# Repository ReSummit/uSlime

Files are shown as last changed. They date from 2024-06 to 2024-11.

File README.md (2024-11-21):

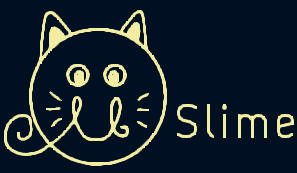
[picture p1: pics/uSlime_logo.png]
<div></div>

Micro form of SlimeVR trackers using BNO085 and ESP32-C6-MINI module, as small as possible

Limited to 1 sided PCB but utilizes two layer to achieve a maximal dimension of 25mm x 28mm (including the ESP32-C6-MINI module)

Also includes some test points if you wanna add idk RGB lights to it or something like that lol

## PCB Variants and Versions

Currently, v1.0.0 is the preferred PCB version and is listed in the releases. As a note, your red charge LED will always be on while the device is on. While this makes for a good indicator that your tracker is on, some may not like that the LED is always on. v1.1.0 fixes this but results in a long trace, change in pinout, and additional components needed.

**If you do not mind the always on LED, use v1.0.0 as it is less likely to result in RF issues. If you are bothered by the LED, use a 2k or higher SMD resistor value or use v1.1.0.**

On variants, there are currently three different types of main board PCBs and 2 types of supplementary modules. The first kind are listed as follows:
* uSlime_PCB: The default PCB with the BNO085 circuit on board. Contains the working BNO085 utilizing the internal crystal (of which there is little room for an external crystal)
* uSlime_PCB_Module: Similar to the default PCB; however, the BNO085 is replaced with a 5 pin I2C pin for attaching a uSlime_BNO085_Module on the back or front side of the PCB (in case you want to replace the IMU with a better one).
* uSlime_PCB_Pack: The default PCB but using pack resistors to attempt the reduction of part placements by quantity. **This has not been updated to v1.0.0 yet, DO NOT USE.**

For supplementary modules, the variants are as follows:
* uSlime_BNO085_Module: The default PCB for supplementary modules. In addition to the connectors that are compatible with the original SlimeVR trackers, they also have headers that you can use to connect it to something else instead if you decide not to use it for SlimeVR. This increases the versatility of the IMU for other projects. Due to the small size, a crystal could not be placed; however, one could be placed with a slightly larger PCB size.
* uSlime_BNO085: The other PCB for supplementary modules without the header pins. This is if you are sure that you are only using this for SlimeVR. You can technically still use this for other projects like with headers, but you will likely solder on wires.

## BOM and Pre-requisites

Bill of materials (BOMs) can be found in the `bom` folder within the respective PCB folder. These are generated on a by release basis, so they may not be up to date. It is highly recommended to generate the BOM using the "`Interactive Html Bom`" plugin found in typical KiCAD repository plugins.  
**Following the BOM placements using a BOM plugin to show where components are placed is mandatory, as there is no space for reference designators on the PCB.**

In addition to this, a hot plate, solder paste, and some needle tipped tweezers are also required. Flux may also be needed to fix any bridges that pop up on the board. Obviously, the components on the BOM are also required.

## Building the PCB

When ordering the PCB, choose to place the JLC PCB indicator as a preferred spot is placed on the PCB itself (if using JLCPCB for PCB production). You should also get a stencil to put solder paste on the PCB.

**Again, following the BOM placements using a BOM plugin to show where components are placed is mandatory, as there is no space for reference designators on the PCB.**
Place solder paste on the PCB. Afterwards, follow the Interactive HTML BOM to place all the capacitors, resistors, IMU, and MCU on the PCB. When ready, you can then place this on a hot plate. Please make sure that there are no bridges on the BNO085 or the USB C connector, as these can cause issues with functionality.

## Verification (MUST READ)

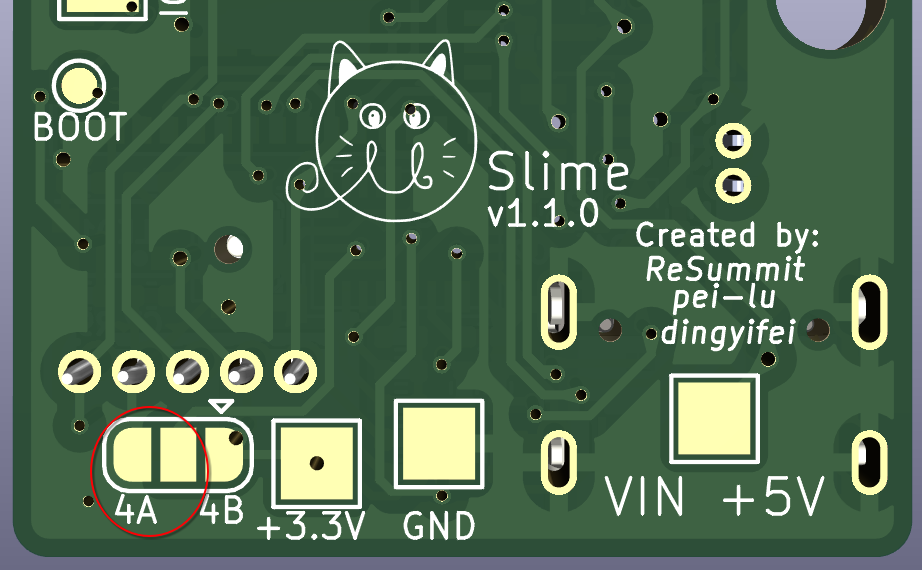
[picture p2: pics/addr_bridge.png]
<div><center>   

**Before testing and using, make sure to bridge the address bridge pads on the back of the PCB.** Verify that the board and the IMU functions by flashing the ESP32-C6 firmware first. If there is no address response, something may be wrong with the IMU (more likely to fail). Once you have verified that the IMU and MCU works, you can then solder the rest of the THT components such as the external IMU connector and battery connector.

## Firmware

The PCB currently uses a ESP32-C6 or equivalent MCU. Right now, there is a pull request to introduce this MCU into the SlimeVR ESP32 firmware located here:  
[SlimeVR ESP32-C6 Pull Request](https://github.com/SlimeVR/SlimeVR-Tracker-ESP/pull/327)

The Arduino core is technically updated but is still pending its full support to the ESP32-C6 line. Therefore, treat this as a beta firmware and subject to broken features or bugs.

## PCB Limitations

Due to the inherent nature of this PCB, there is a chance that this PCB may produce RF. We have not tested for RF emission but regardless, be careful if using this in RF restricted environments.

Also, the main PCB does not have USB voltage protection circuits! Unfortunately, we ran out of time for the release but it is plausible to add it...

In addition, due to the single-sided PCB layout, this is not technically as small as it could be. There have been countless videos that showcase the design possibly being smaller. Some resistor and SMD components can also be moved to the back due to the ease in soldering those components. However, those are slated for a v2.0.0 PCB and is not expected to be released within anytime this year.

Lastly, it is known that the charger SMD compoenent tends to heat up rather quickly while charging the battery. This shouldn't reach the melting point of solder but it is worth mentioning; perhaps a more efficient IC would be better here.

## Images:
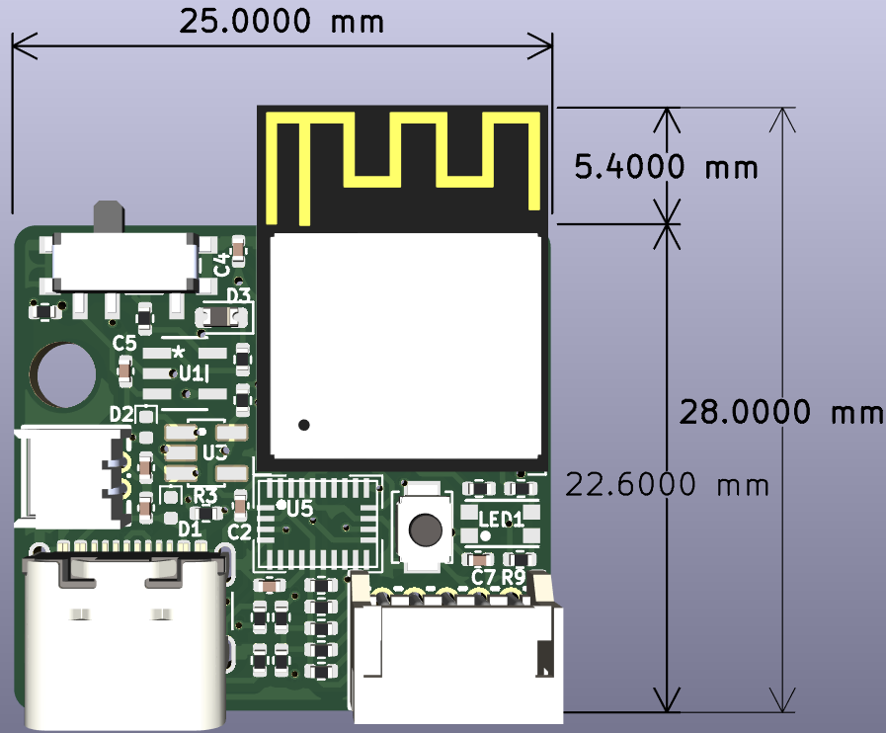
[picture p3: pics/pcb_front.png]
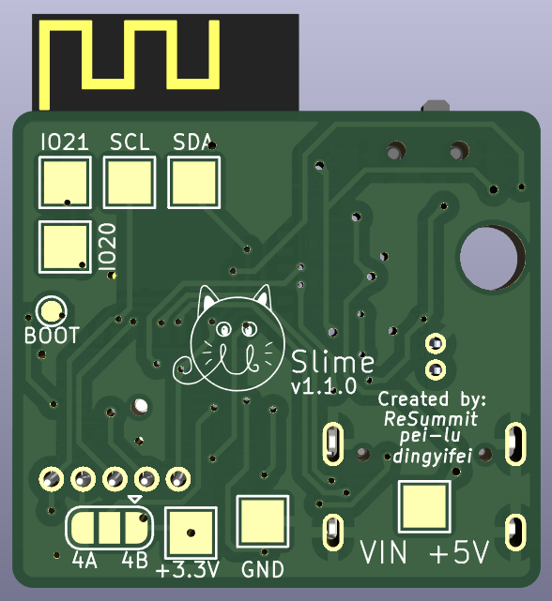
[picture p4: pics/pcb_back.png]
<div></div>

## Footprints Used

Some footprints and symbols were used from other sources:
* ESP32-C6 Symbol: https://github.com/sparkfun/SparkFun_Thing_Plus_ESP32_C6
* ESP32-C6 Footprint: https://github.com/espressif/kicad-libraries
* BNO085 Footprint: Provided by Colin
* AP2112K-3.3TRG1 and MCP73831T-2ACI/OT Symbol / Footprint: From a class project :)
* MHT150RGBCT Footprint: Converted from EasyEDA
* JST ZH Pinout: Same as SlimeVR PCB :D

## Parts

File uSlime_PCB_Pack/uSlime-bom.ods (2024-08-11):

Reference | Value | Datasheet | Footprint | Qty | DNP
CHRG1,STAT1 | LED | ~ | LED_SMD:LED_0402_1005Metric | 2
CN2 | 1.25T-2AW | http://www.szlcsc.com/product/details_157311.html | uSlime-libs:CONN-TH_2P-P1.25_1.25T-2AW | 1
J1 | USB_C_Receptacle_USB2.0_14P | https://www.usb.org/sites/default/files/documents/usb_type-c.zip | Connector_USB:USB_C_Receptacle_GCT_USB4105-xx-A_16P_TopMnt_Horizontal | 1
TP1 | SDA | ~ | TestPoint:TestPoint_Pad_2.0x2.0mm | 1
TP2 | SCL | ~ | TestPoint:TestPoint_Pad_2.0x2.0mm | 1
TP3,TP4 | IO14 | ~ | TestPoint:TestPoint_Pad_2.0x2.0mm | 2
TP5 | 3.3V | ~ | TestPoint:TestPoint_Pad_2.0x2.0mm | 1
TP6 | GND | ~ | TestPoint:TestPoint_Pad_2.0x2.0mm | 1
TP7 | VBUS | ~ | TestPoint:TestPoint_Pad_2.0x2.0mm | 1
U3 | AP2112K-3.3TRG1 |  | uSlime-libs:SOT95P285X140-5N | 1
U4 | MCP73831T-2ACI/OT | MCP73831T-2ACI/OT | uSlime-libs:SOT-23-5_MC_MCH | 1
U5 | BNO085 | BNO085 | uSlime-libs:LGA28_5.2X3.8_CEV | 1
C1,C2,C6,C9 | 0.1uF | ~ | Capacitor_SMD:C_0402_1005Metric | 4
C3,C4,C5 | 10uF | ~ | Capacitor_SMD:C_0402_1005Metric | 3
D1,D2 | D | ~ | Diode_SMD:D_0402_1005Metric | 2
R1 | 100k | ~ | Resistor_SMD:R_0402_1005Metric | 1
R2 | 100k | ~ | Resistor_SMD:R_0402_1005Metric | 1
R3 | 180k | ~ | Resistor_SMD:R_0402_1005Metric | 1
R4,R8 | 1k | ~ | Resistor_SMD:R_0402_1005Metric | 2
R5 | 4.7k | ~ | Resistor_SMD:R_0402_1005Metric | 1
R6,R7 | 5.1k | ~ | Resistor_SMD:R_0402_1005Metric | 2
CN1 | X1502WR-05K-N0SN | http://www.szlcsc.com/product/details_587019.html | uSlime-libs:CONN-TH_5P-P1.50_X1502WR-05K-N0SN | 1
U6 | MSK-12C02_SMD_SPDT_SWITCH |  | uSlime-libs:SW_PCM12SMTR | 1
RESET1 | SW_Push | ~ | Button_Switch_SMD:SW_SPST_B3U-1000P-B | 1
U1 | ESP32-C6-MINI-1 |  | PCM_Espressif:ESP32-C6-MINI-1 | 1

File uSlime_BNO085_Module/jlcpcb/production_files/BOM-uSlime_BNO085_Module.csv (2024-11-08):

Comment | Designator | Footprint | LCSC | Quantity
0.1uF | C1,C2,C3,C4 | C_0402_1005Metric | C141382 | 4
10k | R1,R2,R5 | R_0402_1005Metric | C25744 | 3
2.2k | R3,R4,R6,R7 | R_0402_1005Metric | C25879 | 4
X1502WR-05K-N0SN | CN1 | CONN-TH_5P-P1.50_X1502WR-05K-N0SN | C561537 | 1
Conn_01x05 | J1 | PinHeader_1x05_P2.54mm_Vertical |  | 1
BNO085 | U1 | BNO080 |  | 1

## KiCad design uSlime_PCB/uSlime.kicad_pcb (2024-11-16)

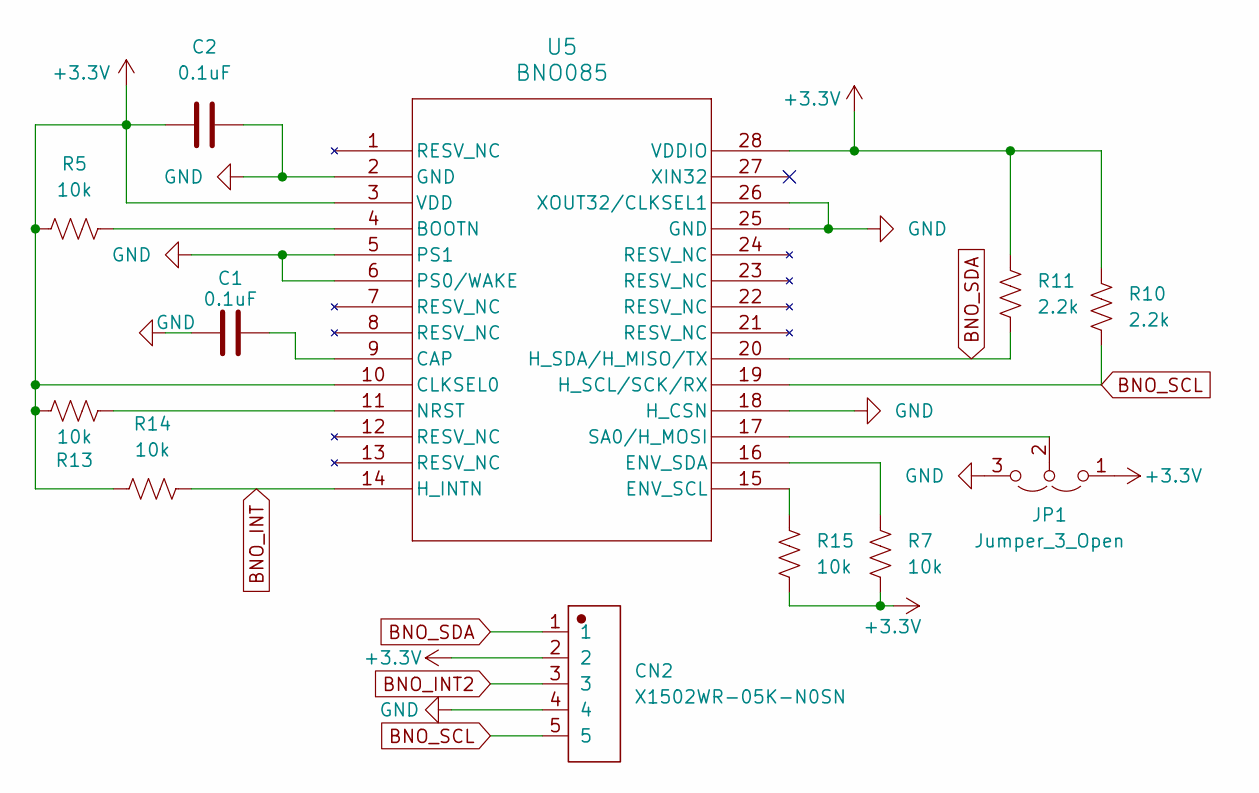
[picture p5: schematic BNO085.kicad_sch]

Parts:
C1, C2: 0.1uF; C_0402_1005Metric
CN2: X1502WR-05K-N0SN; CONN-TH_5P-P1.50_X1502WR-05K-N0SN
JP1: Jumper_3_Open; SolderJumper-3_P1.3mm_Open_RoundedPad1.0x1.5mm
R5, R7, R13, R14, R15: 10k; R_0402_1005Metric
R10, R11: 2.2k; R_0402_1005Metric
U5: BNO085; BNO080

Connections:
+3.3V: C2.1, CN2.2, JP1.1 (A), R5.1, R7.2, R10.1, R11.1, R13.2, R14.1, R15.2, U5.3 (VDD), U5.10 (CLKSEL0), U5.28 (VDDIO); also elsewhere on the board
BNO_INT: R14.2, U5.14 (H_INTN); also elsewhere on the board
BNO_INT2: CN2.3; also elsewhere on the board
BNO_SCL: CN2.5, R10.2, U5.19 (H_SCL/SCK/RX); also elsewhere on the board
BNO_SDA: CN2.1, R11.2, U5.20 (H_SDA/H_MISO/TX); also elsewhere on the board
GND: C1.1, C2.2, CN2.4, JP1.3 (B), U5.2 (GND), U5.5 (PS1), U5.6 (PS0/WAKE), U5.18 (H_CSN), U5.25 (GND), U5.26 (XOUT32/CLKSEL1); also elsewhere on the board
unnamed: JP1.2 (C), U5.17 (SA0/H_MOSI)
unnamed: R5.2, U5.4 (BOOTN)
unnamed: C1.2, U5.9 (CAP)
unnamed: R15.1, U5.15 (ENV_SCL)
unnamed: R7.1, U5.16 (ENV_SDA)
unnamed: R13.1, U5.11 (NRST)

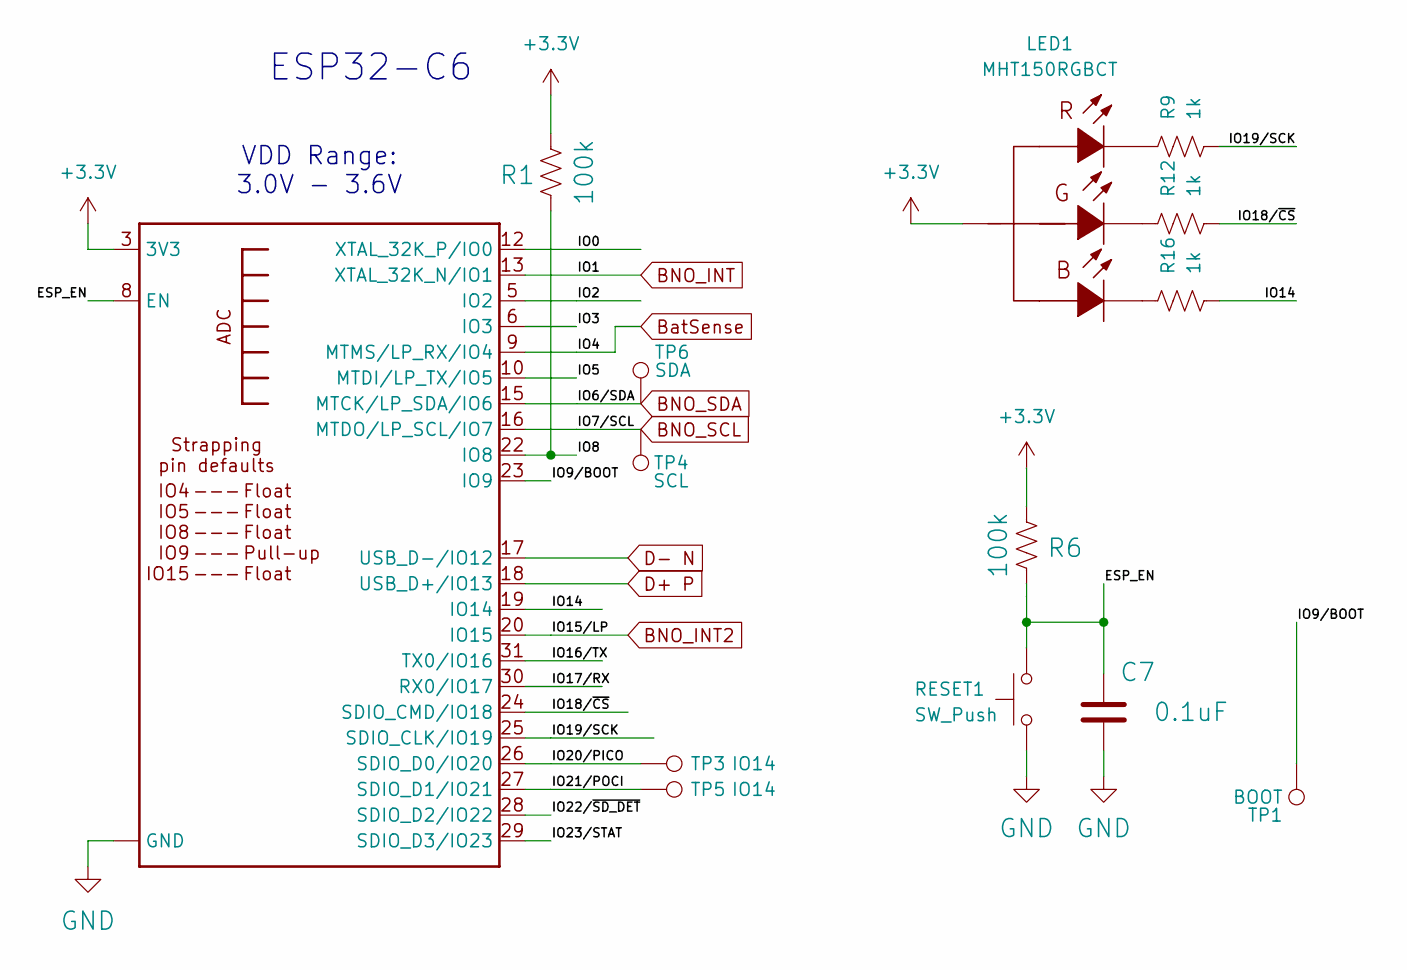
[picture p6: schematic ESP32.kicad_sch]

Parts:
C7: 0.1uF; C_0402_1005Metric
LED1: MHT150RGBCT; LED-ARRAY-SMD_1206-4P-L3.2-W1.3-BR-EH
R1, R6: 100k; R_0402_1005Metric
R9, R12, R16: 1k; R_0402_1005Metric
RESET1: SW_Push; SW_SPST_B3U-1000P-B
TP1: BOOT; TestPoint_Pad_D1.0mm
TP3, TP5: IO14; TestPoint_Pad_2.0x2.0mm
TP4: SCL; TestPoint_Pad_2.0x2.0mm
TP6: SDA; TestPoint_Pad_2.0x2.0mm
U4: ESP32-C6-MINI-1

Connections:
+3.3V: LED1.1 (+), R1.2, R6.2, U4.3 (3V3); also elsewhere on the board
/ESP32-C6FH4/ESP_EN: C7.1, R6.1, RESET1.2, U4.8 (EN)
/ESP32-C6FH4/IO0: U4.12 (XTAL_32K_P/IO0)
/ESP32-C6FH4/IO2: U4.5 (IO2)
/ESP32-C6FH4/IO3: U4.6 (IO3)
/ESP32-C6FH4/IO5: U4.10 (MTDI/LP_TX/IO5)
/ESP32-C6FH4/IO8: R1.1, U4.22 (IO8)
/ESP32-C6FH4/IO14: R16.1, U4.19 (IO14)
/ESP32-C6FH4/IO16/TX: U4.31 (TX0/IO16)
/ESP32-C6FH4/IO17/RX: U4.30 (RX0/IO17)
/ESP32-C6FH4/IO18/~CS: R12.1, U4.24 (SDIO_CMD/IO18)
/ESP32-C6FH4/IO19/SCK: R9.1, U4.25 (SDIO_CLK/IO19)
/ESP32-C6FH4/IO20/PICO: TP3.1, U4.26 (SDIO_D0/IO20)
/ESP32-C6FH4/IO21/POCI: TP5.1, U4.27 (SDIO_D1/IO21)
/ESP32-C6FH4/IO22/~SD_DET: U4.28 (SDIO_D2/IO22)
/ESP32-C6FH4/IO23/STAT: U4.29 (SDIO_D3/IO23)
BNO_INT: U4.13 (XTAL_32K_N/IO1); also elsewhere on the board
BNO_INT2: U4.20 (IO15); also elsewhere on the board
BNO_SCL: TP4.1, U4.16 (MTDO/LP_SCL/IO7); also elsewhere on the board
BNO_SDA: TP6.1, U4.15 (MTCK/LP_SDA/IO6); also elsewhere on the board
BatSense: U4.9 (MTMS/LP_RX/IO4); also elsewhere on the board
D+ P: U4.18 (USB_D+/IO13); also elsewhere on the board
D- N: U4.17 (USB_D-/IO12); also elsewhere on the board
GND: C7.2, RESET1.1, U4.1 (GND), U4.2 (GND), U4.11 (GND), U4.14 (GND), U4.36 (GND), U4.37 (GND), U4.38 (GND), U4.39 (GND), U4.40 (GND), U4.41 (GND), U4.42 (GND), U4.43 (GND), U4.44 (GND), U4.45 (GND), U4.46 (GND), U4.47 (GND), U4.48 (GND), U4.49 (GND), U4.50 (GND), U4.51 (GND), U4.52 (GND), U4.53 (GND); also elsewhere on the board
unnamed: LED1.2 (-), R16.2
unnamed: LED1.3 (-), R12.2
unnamed: LED1.4 (-), R9.2

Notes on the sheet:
ESP32-C6
VDD Range: 3.0V - 3.6V

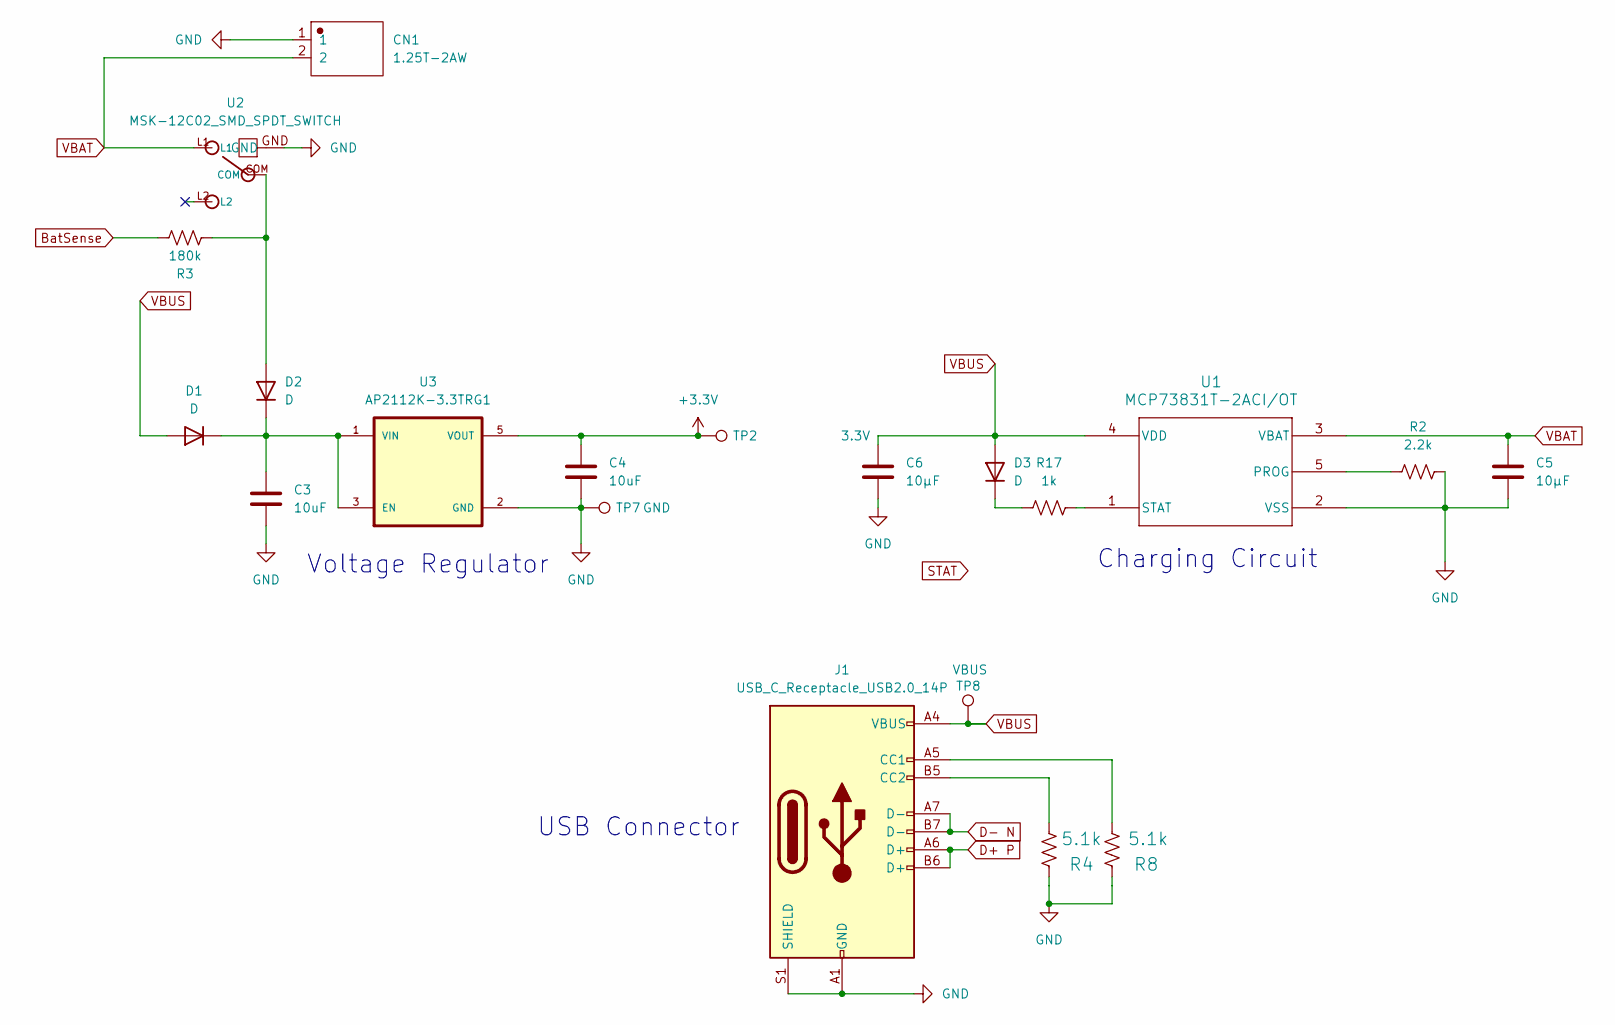
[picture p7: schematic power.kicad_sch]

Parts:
C3, C4: 10uF; C_0402_1005Metric
C5, C6: 10μF; C_0402_1005Metric
CN1: 1.25T-2AW; CONN-TH_2P-P1.25_1.25T-2AW
D1, D2: D; D_0402_1005Metric
D3: D; D_0603_1608Metric
J1: USB_C_Receptacle_USB2.0_14P; USB_C_Receptacle_GCT_USB4105-xx-A_16P_TopMnt_Horizontal
R2: 2.2k; R_0402_1005Metric
R3: 180k; R_0402_1005Metric
R4, R8: 5.1k; R_0402_1005Metric
R17: 1k; R_0402_1005Metric
TP2: 3.3V; TestPoint_Pad_2.0x2.0mm
TP7: GND; TestPoint_Pad_2.0x2.0mm
TP8: VBUS; TestPoint_Pad_2.0x2.0mm
U1: MCP73831T-2ACI/OT; SOT-23-5_MC_MCH
U2: MSK-12C02_SMD_SPDT_SWITCH; SW_PCM12SMTR
U3: AP2112K-3.3TRG1; SOT95P285X140-5N; PARTREV 2-2

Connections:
+3.3V: C4.1, TP2.1, U3.5 (VOUT); also elsewhere on the board
BatSense: R3.2; also elsewhere on the board
D+ P: J1.A6 (D+), J1.B6 (D+); also elsewhere on the board
D- N: J1.A7 (D-), J1.B7 (D-); also elsewhere on the board
GND: C3.2, C4.2, C5.2, C6.2, CN1.1, J1.A1 (GND), J1.A12 (GND), J1.B1 (GND), J1.B12 (GND), J1.S1 (SHIELD), R2.2, R4.1, R8.1, TP7.1, U1.2 (VSS), U2.GND, U3.2 (GND); also elsewhere on the board
unnamed: C3.1, D1.1 (K), D2.1 (K), U3.1 (VIN), U3.3 (EN)
unnamed: D2.2 (A), R3.1, U2.COM
unnamed: D3.1 (K), R17.1
unnamed: J1.A5 (CC1), R8.2
unnamed: J1.B5 (CC2), R4.2
unnamed: R2.1, U1.5 (PROG)
unnamed: R17.2, U1.1 (STAT)
VBAT: C5.1, CN1.2, U1.3 (VBAT), U2.L1
VBUS: C6.1, D1.2 (A), D3.2 (A), J1.A4 (VBUS), J1.A9 (VBUS), J1.B4 (VBUS), J1.B9 (VBUS), TP8.1, U1.4 (VDD)

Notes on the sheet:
Charging Circuit
Voltage Regulator
USB Connector

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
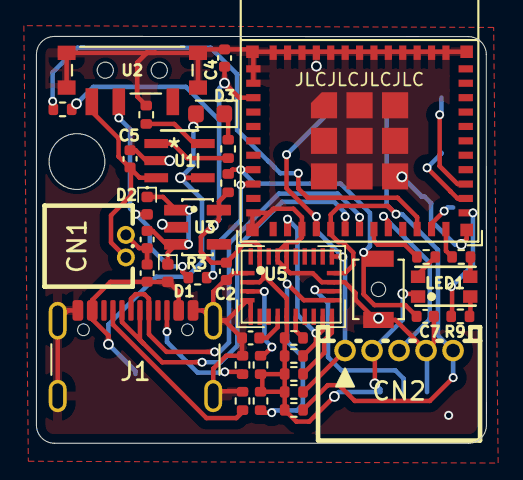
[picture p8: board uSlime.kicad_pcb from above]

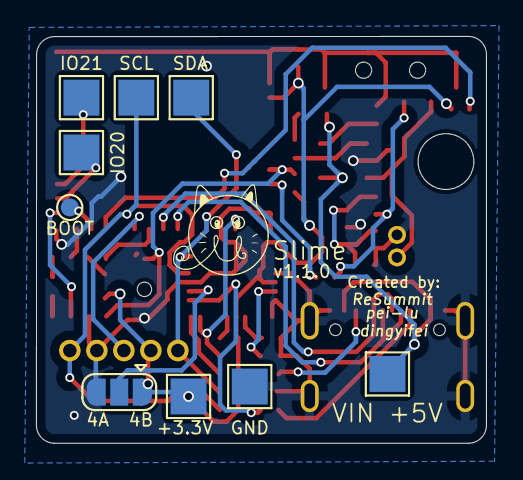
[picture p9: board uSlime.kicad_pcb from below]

Board: 2 copper layers, 25.0 x 22.6 mm, 46 parts (9 on the bottom side), 35 nets.

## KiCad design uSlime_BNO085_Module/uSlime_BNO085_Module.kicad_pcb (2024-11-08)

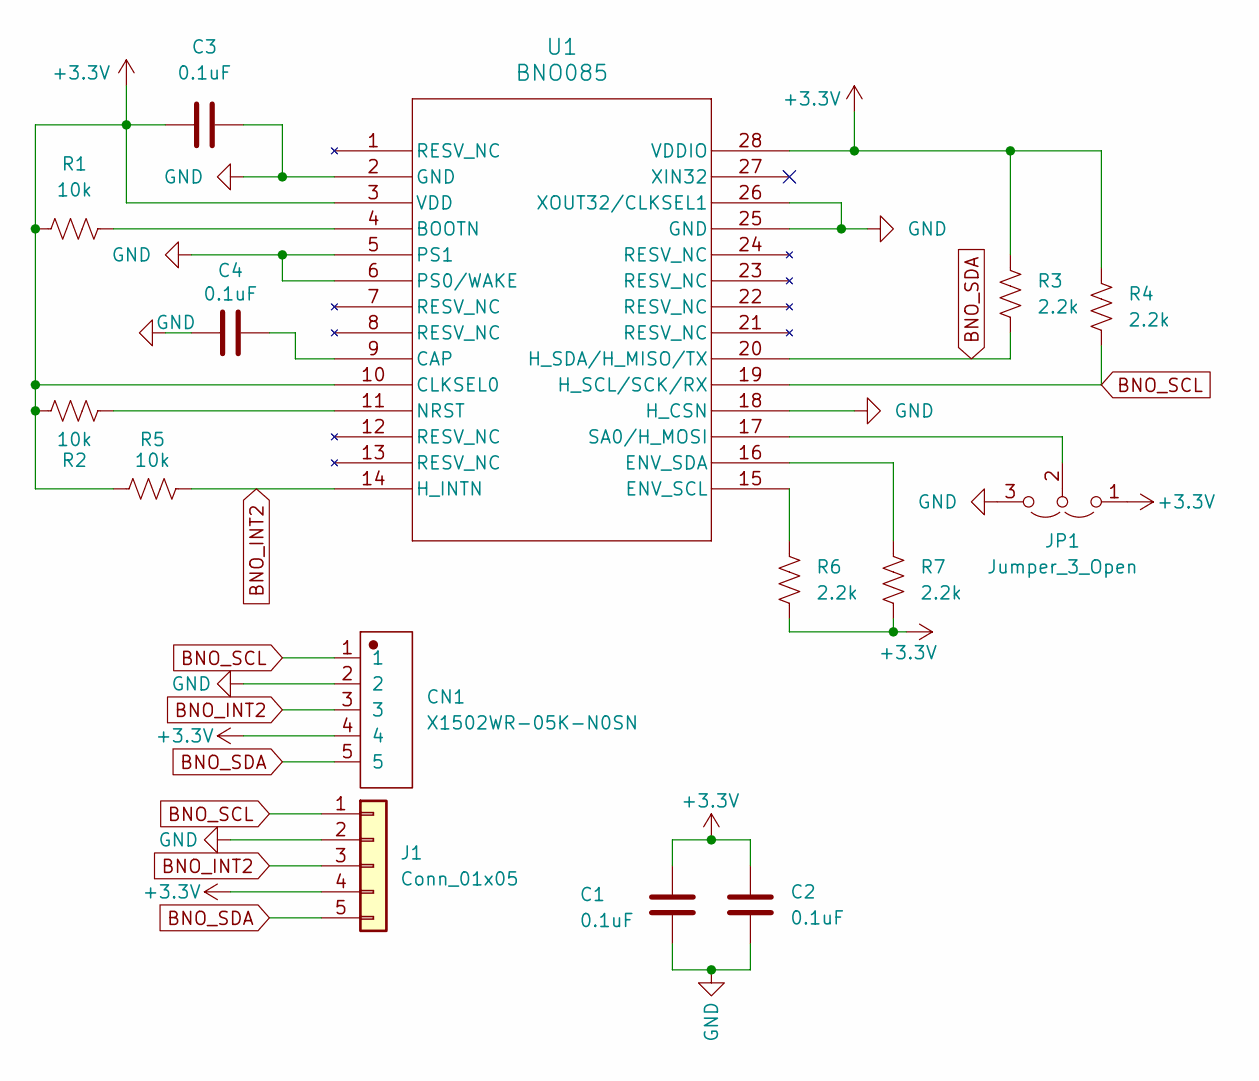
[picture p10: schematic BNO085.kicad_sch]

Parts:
C1, C2, C3, C4: 0.1uF; C_0402_1005Metric
CN1: X1502WR-05K-N0SN; CONN-TH_5P-P1.50_X1502WR-05K-N0SN
J1: Conn_01x05; PinHeader_1x05_P2.54mm_Vertical
JP1: Jumper_3_Open; SolderJumper-3_P1.3mm_Open_RoundedPad1.0x1.5mm
R1, R2, R5: 10k; R_0402_1005Metric
R3, R4, R6, R7: 2.2k; R_0402_1005Metric
U1: BNO085; BNO080

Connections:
+3.3V: C1.2, C2.2, C3.1, CN1.4, J1.4, JP1.1 (A), R1.1, R2.2, R3.1, R4.1, R5.1, R6.2, R7.2, U1.3 (VDD), U1.10 (CLKSEL0), U1.28 (VDDIO)
BNO_INT2: CN1.3, J1.3, R5.2, U1.14 (H_INTN)
BNO_SCL: CN1.1, J1.1, R4.2, U1.19 (H_SCL/SCK/RX)
BNO_SDA: CN1.5, J1.5, R3.2, U1.20 (H_SDA/H_MISO/TX)
GND: C1.1, C2.1, C3.2, C4.1, CN1.2, J1.2, JP1.3 (B), U1.2 (GND), U1.5 (PS1), U1.6 (PS0/WAKE), U1.18 (H_CSN), U1.25 (GND), U1.26 (XOUT32/CLKSEL1)
unnamed: JP1.2 (C), U1.17 (SA0/H_MOSI)
unnamed: R1.2, U1.4 (BOOTN)
unnamed: C4.2, U1.9 (CAP)
unnamed: R6.1, U1.15 (ENV_SCL)
unnamed: R7.1, U1.16 (ENV_SDA)
unnamed: R2.1, U1.11 (NRST)

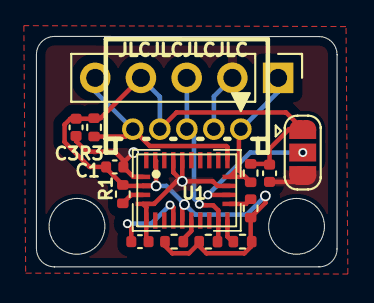
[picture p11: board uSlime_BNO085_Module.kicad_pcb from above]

Board: 2 copper layers, 16.7 x 12.8 mm, 15 parts (0 on the bottom side), 11 nets.

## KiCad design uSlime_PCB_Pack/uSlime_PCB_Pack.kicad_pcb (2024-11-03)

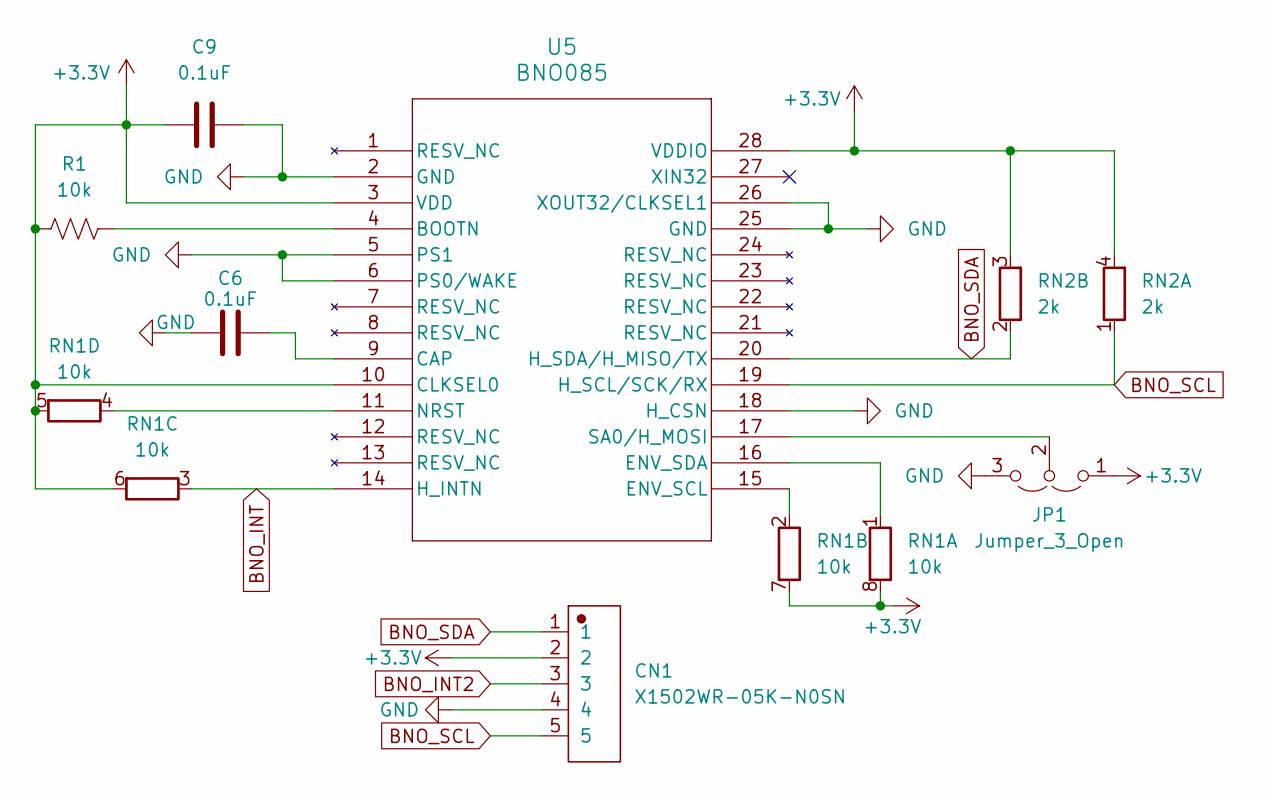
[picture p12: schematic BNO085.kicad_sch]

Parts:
C6, C9: 0.1uF; C_0402_1005Metric
CN1: X1502WR-05K-N0SN; CONN-TH_5P-P1.50_X1502WR-05K-N0SN
JP1: Jumper_3_Open; SolderJumper-3_P1.3mm_Open_RoundedPad1.0x1.5mm
R1: 10k; R_0402_1005Metric
RN1: 10k; R_Array_Convex_4x0402
RN2: 2k; R_Array_Convex_2x0402
U5: BNO085; BNO080

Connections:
+3.3V: C9.1, CN1.2, JP1.1 (A), R1.1, RN1.5 (R4.2), RN1.6 (R3.2), RN1.7 (R2.2), RN1.8 (R1.2), RN2.3 (R2.2), RN2.4 (R1.2), U5.3 (VDD), U5.10 (CLKSEL0), U5.28 (VDDIO); also elsewhere on the board
BNO_INT: RN1.3 (R3.1), U5.14 (H_INTN); also elsewhere on the board
BNO_INT2: CN1.3; also elsewhere on the board
BNO_SCL: CN1.5, RN2.1 (R1.1), U5.19 (H_SCL/SCK/RX); also elsewhere on the board
BNO_SDA: CN1.1, RN2.2 (R2.1), U5.20 (H_SDA/H_MISO/TX); also elsewhere on the board
GND: C6.1, C9.2, CN1.4, JP1.3 (B), U5.2 (GND), U5.5 (PS1), U5.6 (PS0/WAKE), U5.18 (H_CSN), U5.25 (GND), U5.26 (XOUT32/CLKSEL1); also elsewhere on the board
unnamed: JP1.2 (C), U5.17 (SA0/H_MOSI)
unnamed: RN1.1 (R1.1), U5.16 (ENV_SDA)
unnamed: RN1.2 (R2.1), U5.15 (ENV_SCL)
unnamed: RN1.4 (R4.1), U5.11 (NRST)
unnamed: R1.2, U5.4 (BOOTN)
unnamed: C6.2, U5.9 (CAP)

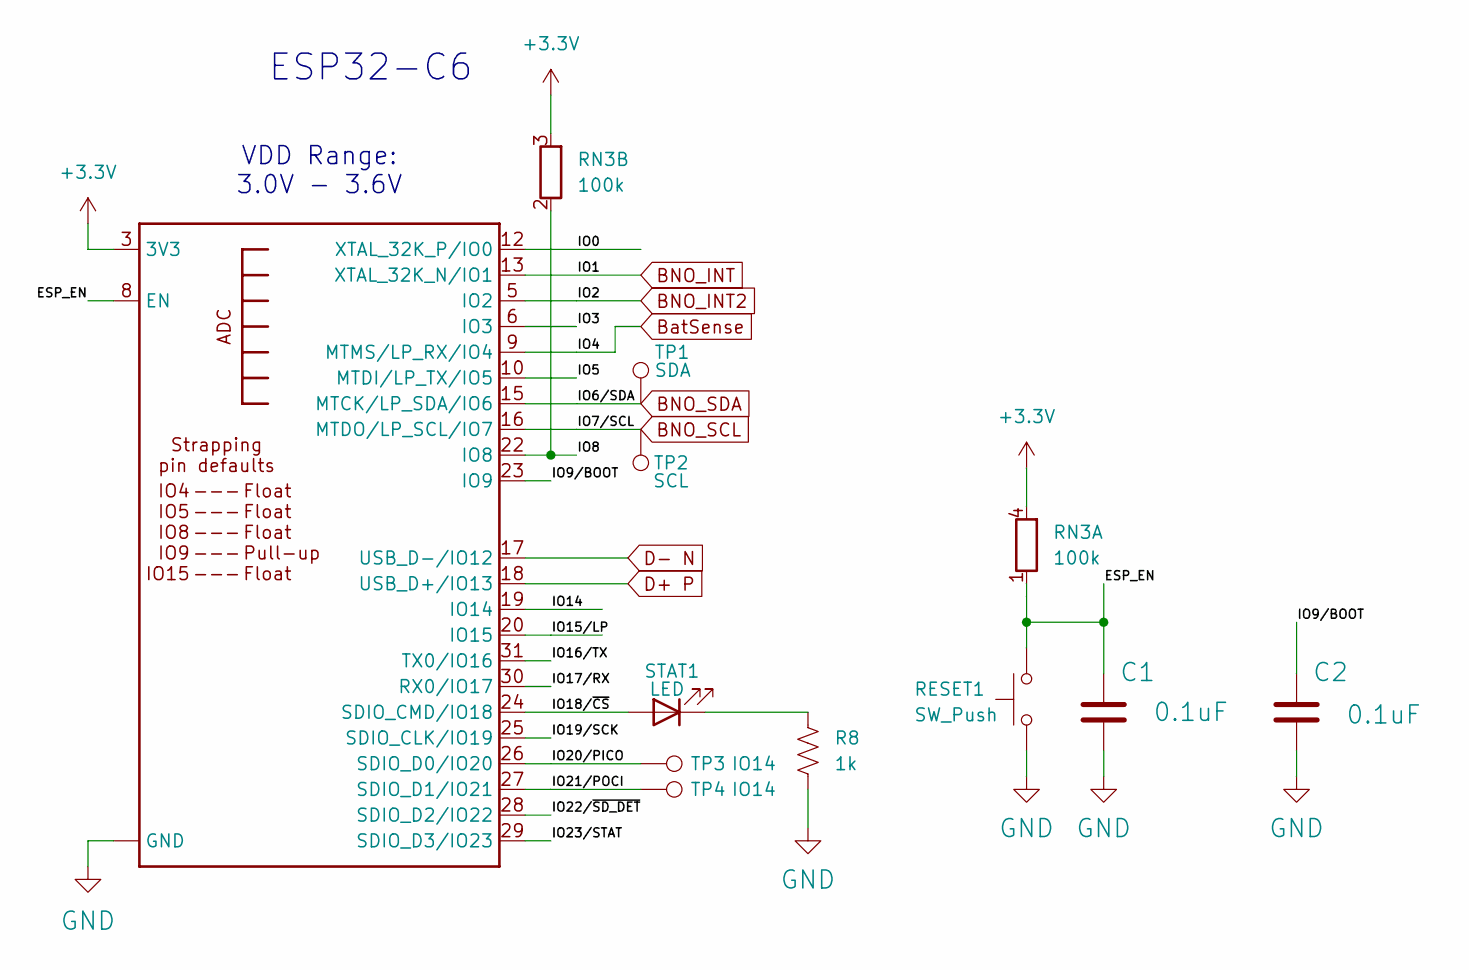
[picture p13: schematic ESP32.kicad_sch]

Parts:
C1, C2: 0.1uF; C_0402_1005Metric
R8: 1k; R_0402_1005Metric
RESET1: SW_Push; SW_SPST_B3U-1000P-B
RN3: 100k; R_Array_Convex_2x0402
STAT1: LED; LED_0402_1005Metric
TP1: SDA; TestPoint_Pad_2.0x2.0mm
TP2: SCL; TestPoint_Pad_2.0x2.0mm
TP3, TP4: IO14; TestPoint_Pad_2.0x2.0mm
U1: ESP32-C6-MINI-1

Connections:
+3.3V: RN3.3 (R2.2), RN3.4 (R1.2), U1.3 (3V3); also elsewhere on the board
/ESP32-C6FH4/ESP_EN: C1.1, RESET1.2, RN3.1 (R1.1), U1.8 (EN)
/ESP32-C6FH4/IO0: U1.12 (XTAL_32K_P/IO0)
/ESP32-C6FH4/IO3: U1.6 (IO3)
/ESP32-C6FH4/IO5: U1.10 (MTDI/LP_TX/IO5)
/ESP32-C6FH4/IO8: RN3.2 (R2.1), U1.22 (IO8)
/ESP32-C6FH4/IO14: U1.19 (IO14)
/ESP32-C6FH4/IO15/LP: U1.20 (IO15)
/ESP32-C6FH4/IO16/TX: U1.31 (TX0/IO16)
/ESP32-C6FH4/IO17/RX: U1.30 (RX0/IO17)
/ESP32-C6FH4/IO18/~CS: STAT1.2 (A), U1.24 (SDIO_CMD/IO18)
/ESP32-C6FH4/IO19/SCK: U1.25 (SDIO_CLK/IO19)
/ESP32-C6FH4/IO20/PICO: TP3.1, U1.26 (SDIO_D0/IO20)
/ESP32-C6FH4/IO21/POCI: TP4.1, U1.27 (SDIO_D1/IO21)
/ESP32-C6FH4/IO22/~SD_DET: U1.28 (SDIO_D2/IO22)
/ESP32-C6FH4/IO23/STAT: U1.29 (SDIO_D3/IO23)
BNO_INT: U1.13 (XTAL_32K_N/IO1); also elsewhere on the board
BNO_INT2: U1.5 (IO2); also elsewhere on the board
BNO_SCL: TP2.1, U1.16 (MTDO/LP_SCL/IO7); also elsewhere on the board
BNO_SDA: TP1.1, U1.15 (MTCK/LP_SDA/IO6); also elsewhere on the board
BatSense: U1.9 (MTMS/LP_RX/IO4); also elsewhere on the board
D+ P: U1.18 (USB_D+/IO13); also elsewhere on the board
D- N: U1.17 (USB_D-/IO12); also elsewhere on the board
GND: C1.2, C2.2, R8.1, RESET1.1, U1.1 (GND), U1.2 (GND), U1.11 (GND), U1.14 (GND), U1.36 (GND), U1.37 (GND), U1.38 (GND), U1.39 (GND), U1.40 (GND), U1.41 (GND), U1.42 (GND), U1.43 (GND), U1.44 (GND), U1.45 (GND), U1.46 (GND), U1.47 (GND), U1.48 (GND), U1.49 (GND), U1.50 (GND), U1.51 (GND), U1.52 (GND), U1.53 (GND); also elsewhere on the board
unnamed: R8.2, STAT1.1 (K)

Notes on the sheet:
ESP32-C6
VDD Range: 3.0V - 3.6V

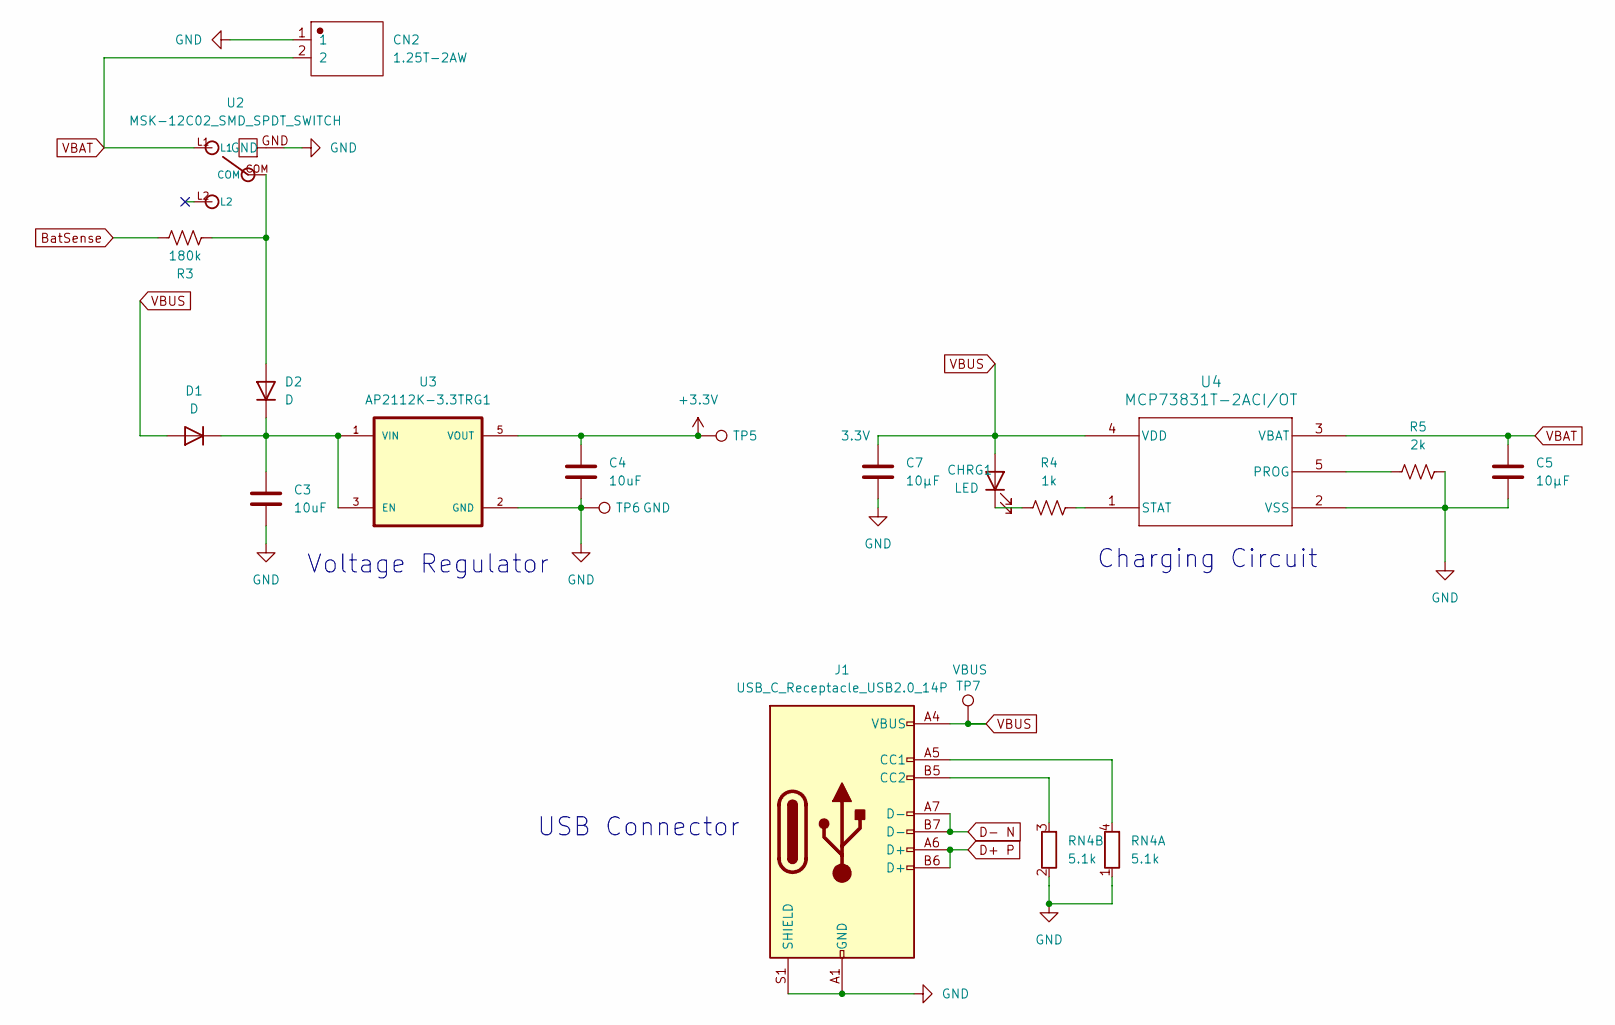
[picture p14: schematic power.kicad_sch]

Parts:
C3, C4: 10uF; C_0402_1005Metric
C5, C7: 10μF; C_0402_1005Metric
CHRG1: LED; LED_0402_1005Metric
CN2: 1.25T-2AW; CONN-TH_2P-P1.25_1.25T-2AW
D1, D2: D; D_0402_1005Metric
J1: USB_C_Receptacle_USB2.0_14P; USB_C_Receptacle_GCT_USB4105-xx-A_16P_TopMnt_Horizontal
R3: 180k; R_0402_1005Metric
R4: 1k; R_0402_1005Metric
R5: 2k; R_0402_1005Metric
RN4: 5.1k; R_Array_Convex_2x0402
TP5: 3.3V; TestPoint_Pad_2.0x2.0mm
TP6: GND; TestPoint_Pad_2.0x2.0mm
TP7: VBUS; TestPoint_Pad_2.0x2.0mm
U2: MSK-12C02_SMD_SPDT_SWITCH; SW_PCM12SMTR
U3: AP2112K-3.3TRG1; SOT95P285X140-5N; PARTREV 2-2
U4: MCP73831T-2ACI/OT; SOT-23-5_MC_MCH

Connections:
+3.3V: C4.1, TP5.1, U3.5 (VOUT); also elsewhere on the board
BatSense: R3.2; also elsewhere on the board
D+ P: J1.A6 (D+), J1.B6 (D+); also elsewhere on the board
D- N: J1.A7 (D-), J1.B7 (D-); also elsewhere on the board
GND: C3.2, C4.2, C5.2, C7.2, CN2.1, J1.A1 (GND), J1.A12 (GND), J1.B1 (GND), J1.B12 (GND), J1.S1 (SHIELD), R5.2, RN4.1 (R1.1), RN4.2 (R2.1), TP6.1, U2.GND, U3.2 (GND), U4.2 (VSS); also elsewhere on the board
unnamed: CHRG1.1 (K), R4.1
unnamed: C3.1, D1.1 (K), D2.1 (K), U3.1 (VIN), U3.3 (EN)
unnamed: D2.2 (A), R3.1, U2.COM
unnamed: J1.A5 (CC1), RN4.4 (R1.2)
unnamed: J1.B5 (CC2), RN4.3 (R2.2)
unnamed: R5.1, U4.5 (PROG)
unnamed: R4.2, U4.1 (STAT)
VBAT: C5.1, CN2.2, U2.L1, U4.3 (VBAT)
VBUS: C7.1, CHRG1.2 (A), D1.2 (A), J1.A4 (VBUS), J1.A9 (VBUS), J1.B4 (VBUS), J1.B9 (VBUS), TP7.1, U4.4 (VDD)

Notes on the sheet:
Charging Circuit
Voltage Regulator
USB Connector

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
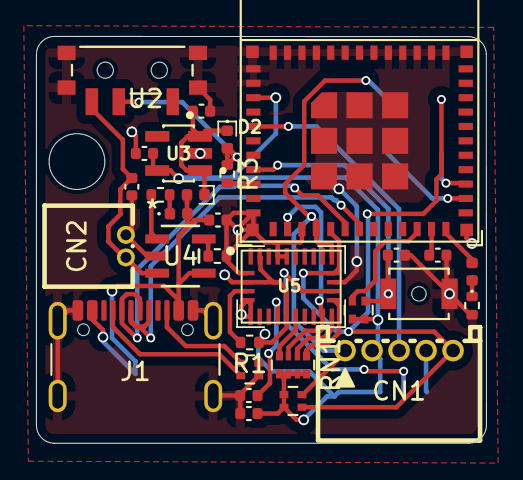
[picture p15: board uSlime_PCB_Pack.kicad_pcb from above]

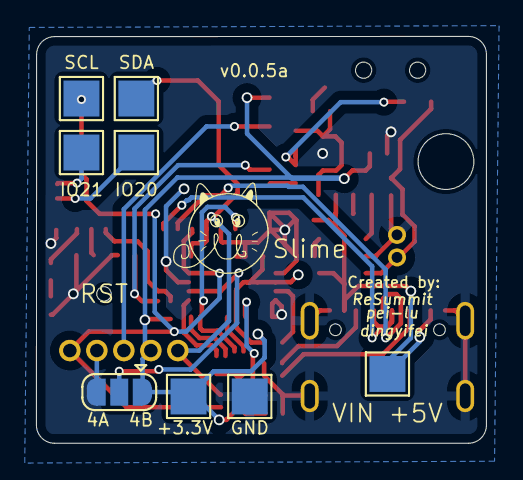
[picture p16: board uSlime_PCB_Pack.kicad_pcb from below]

Board: 2 copper layers, 25.0 x 22.6 mm, 38 parts (8 on the bottom side), 31 nets.

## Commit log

2024-05-10 Init Kicad
    [uSlime.kicad_pcb, uSlime.kicad_sch]
2024-05-10 Add hierarchy for power and ESP32
    [ESP32.kicad_sch, power.kicad_sch, uSlime.kicad_pcb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]
2024-05-17 Insert ESP32-C6FH4
    [BNO085.kicad_sch, ESP32.kicad_sch, uSlime.kicad_sch]
2024-05-17 add power circuit
    [power.kicad_sch]
2024-05-17 Update schematic and libraries
    [BNO085.kicad_sch, ESP32.kicad_sch, power.kicad_sch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]
2024-05-17 Update footprints
    [uSlime.kicad_sch]
2024-05-21 Modify ESP32
    [BNO085.kicad_sch, ESP32.kicad_sch, uSlime.kicad_pcb]
2024-05-21 1st attempt finish BNO085
    [BNO085.kicad_sch]
2024-05-21 Update PCB
    [uSlime.kicad_pcb]
2024-05-22 update power supply
    [power.kicad_sch]
2024-05-23 Add switches, change PCB
    [BNO085.kicad_sch, ESP32.kicad_sch, power.kicad_sch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]
2024-05-24 update power
    [BNO085.kicad_sch, ESP32.kicad_sch, power.kicad_sch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]
2024-05-26 Modify ESP32 connections
    [ESP32.kicad_sch, uSlime.kicad_pcb]
2024-05-26 Recover old power schematic
    [power.kicad_sch]
2024-05-26 Replace ESP32 symbol with right ESP32
    [ESP32.kicad_sch, power.kicad_sch, uSlime.kicad_pcb]
2024-05-26 Condense schematic
    [BNO085.kicad_sch, ESP32.kicad_sch, power.kicad_sch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]
2024-05-26 PCB Smol Time
    [ESP32.kicad_sch, power.kicad_sch, uSlime.kicad_pcb]
2024-05-26 Cleanup extra files
    [uSlime.kicad_pcb, uSlime.kicad_sch]
2024-05-26 Add connector for testing
    [BNO085.kicad_sch, uSlime.kicad_pcb]
2024-05-26 Add fiducial
    [uSlime.kicad_pcb]
2024-05-27 update power circuit
    [power.kicad_sch]
2024-05-27 update battery sense
    [ESP32.kicad_sch, power.kicad_sch]
2024-05-27 Create prelim PCB
    [BNO085.kicad_sch, ESP32.kicad_sch, power.kicad_sch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]
2024-05-27 Add status LED
    [ESP32.kicad_sch, uSlime.kicad_pcb]
2024-05-28 2nd version but smaller at 25x28
    [BNO085.kicad_sch, ESP32.kicad_sch, power.kicad_sch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]
2024-05-28 Fix some DRC and generate gerber
    Some errors popped up on annular diameter, fixed and generated gerber
    files for production
    [uSlime-B_Cu.gbl, uSlime-B_Mask.gbs, uSlime-B_Paste.gbp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]
2024-05-28 Add some jlcpcb BOM info and zip
2024-05-29 Add logo and remove crystal
    [BNO085.kicad_sch, ESP32.kicad_sch, power.kicad_sch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]
2024-05-29 Rearrange capacitor silkscreen
    [uSlime.kicad_pcb]
2024-06-03 Add NC points
    [BNO085.kicad_sch, power.kicad_sch, uSlime.kicad_pcb]
2024-06-03 Add prelim BOM
    [uSlime-bom.csv]
2024-06-05 Revamp pwr resistor, cap placement, fix switch sym
    Fix placement of resistors and capacitor placement b/c additional
    components were added to power circuit and weren't correct...
    Also fixed switch symbol so wires actually connect to it in schematic
    [ESP32.kicad_sch, power.kicad_sch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]
2024-06-05 Add gerber zip
2024-06-06 Add BNO085 PCB, restructure folders
    [BNO085.kicad_sch, ESP32.kicad_sch, power.kicad_sch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]
2024-06-06 Fix weird submodule reference
    [BNO085.kicad_sch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]
2024-06-06 Add pics and logo
    [uSlime.kicad_pcb]
2024-07-25 Faulty BNO085 footprint
    First, I do not like you UltraLibrarian anymore, for you have wasted a
    lot of time and effort (and money) on footprints that are just straight
    up wrong. I am this close to unleashing unbridled rage on this but will
    bottle it up for now.
    Second, I took the BNO085 footprint from the official SlimeVR tracker
    and put it in this project. At least they have the right footprint...
    Stencils for the main microcontroller does not need to change but the
    extension module got a revamp in favor of being more versatile. You can
    now choose which I2C address the sensor operates on; just make sure you
    bridge the right contacts.
    [BNO085.kicad_sch, ESP32.kicad_sch, power.kicad_sch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]
2024-07-25 Add version number v0.0.1a
    [uSlime-B_Cu.gbl, uSlime-B_Mask.gbs, uSlime-B_Paste.gbp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]
2024-08-09 update selection i2c
    [BNO085.kicad_sch]
2024-08-11 update schmetic
    fix pull up
    [BNO085.kicad_sch]
2024-08-11 Update main board BNO
    [BNO085.kicad_sch, ESP32.kicad_sch, power.kicad_sch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]
2024-08-13 Update main PCB schematic
    [BNO085.kicad_sch, power.kicad_sch, uSlime.kicad_pcb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]
2024-08-14 v0.0.2a Modify BNO I2C
    [BNO085.kicad_sch, ESP32.kicad_sch, power.kicad_sch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]
2024-08-17 update gbr file
    [uSlime-B_Cu.gbl, uSlime-B_Mask.gbs, uSlime-B_Paste.gbp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]
2024-08-22 v0.0.3a Fix wrong I2C address for 0x4A
    [BNO085.kicad_sch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]
2024-08-23 Change bat sense pin to not IO0
    [ESP32.kicad_sch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]
2024-08-30 Fix BNO wrong pin order
    [BNO085.kicad_sch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]
2024-09-20 Connect DI without resistor
    [BNO085.kicad_sch, ESP32.kicad_sch, power.kicad_sch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]
2024-09-20 Add models for SMD, STEP of PCB
    [uSlime.kicad_pcb]
2024-10-20 v0.0.5: Invert CLKSEL pin to 3.3V
    [BNO085.kicad_sch, ESP32.kicad_sch, power.kicad_sch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]
2024-10-21 Add module version
    [BNO085.kicad_sch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]
2024-10-22 Connect pin 26 to GND
    [BNO085.kicad_sch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]
2024-10-22 Add dingyifei to PCB ref
    [uSlime-B_Cu.gbl, uSlime-B_Mask.gbs, uSlime-B_Paste.gbp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]
2024-10-23 update schmetic
    [BNO085.kicad_sch]
2024-10-24 Modify PCB to add resistors to pins 14, 15, 16
    [BNO085.kicad_sch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]
2024-11-03 Push pack resistor variant
    [BNO085.kicad_sch, ESP32.kicad_sch, power.kicad_sch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]
2024-11-03 v1.0.0 - Use 1206 LED, add resistor pack suggestion
    [BNO085.kicad_sch, ESP32.kicad_sch, power.kicad_sch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]
2024-11-03 Remove GPIO9 capacitor causing boot problems
    [BNO085.kicad_sch, ESP32.kicad_sch, power.kicad_sch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]
2024-11-08 Add JLCPCB associated parts
    [BOM-uSlime_BNO085_Module.csv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]
2024-11-08 Export mainboard PCB for JLC ident placement
    [uSlime-B_Cu.gbl, uSlime-B_Mask.gbs, uSlime-B_Paste.gbp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]
2024-11-16 Change charge LED to 2.2k, always on light if not charging
    [ESP32.kicad_sch, uSlime.kicad_pcb]
2024-11-16 v1.1.0 - Add 603 LED and resistor for charger status
    [ESP32.kicad_sch, power.kicad_sch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]
2024-11-16 Forgot to change silkscreen positions
    [uSlime-B_Cu.gbl, uSlime-B_Mask.gbs, uSlime-B_Paste.gbp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]
2024-11-21 Add footprint sources
